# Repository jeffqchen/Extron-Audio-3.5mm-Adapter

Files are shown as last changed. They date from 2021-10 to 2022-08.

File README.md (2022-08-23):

# Extron Audio 3.5mm Adapter
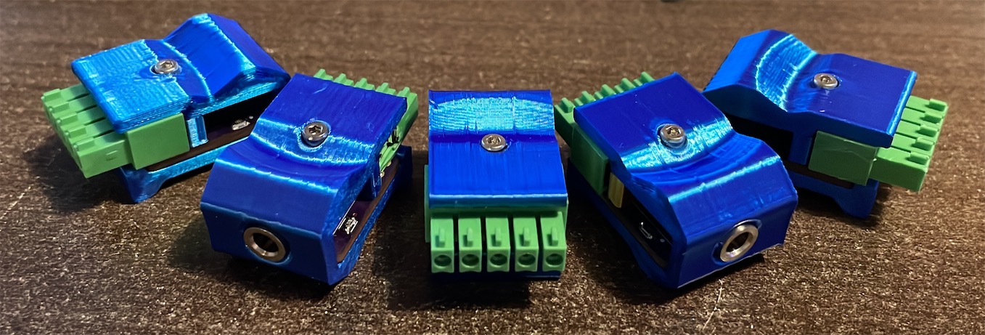
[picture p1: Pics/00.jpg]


This is an 3.5mm audio input/output adapter for the Extron switches. It conforms to the circuit design of the official CSM6 adapter to enable correct audio levels when balanced audio is adapted to unbalanced audio through a 3.5mm jack.

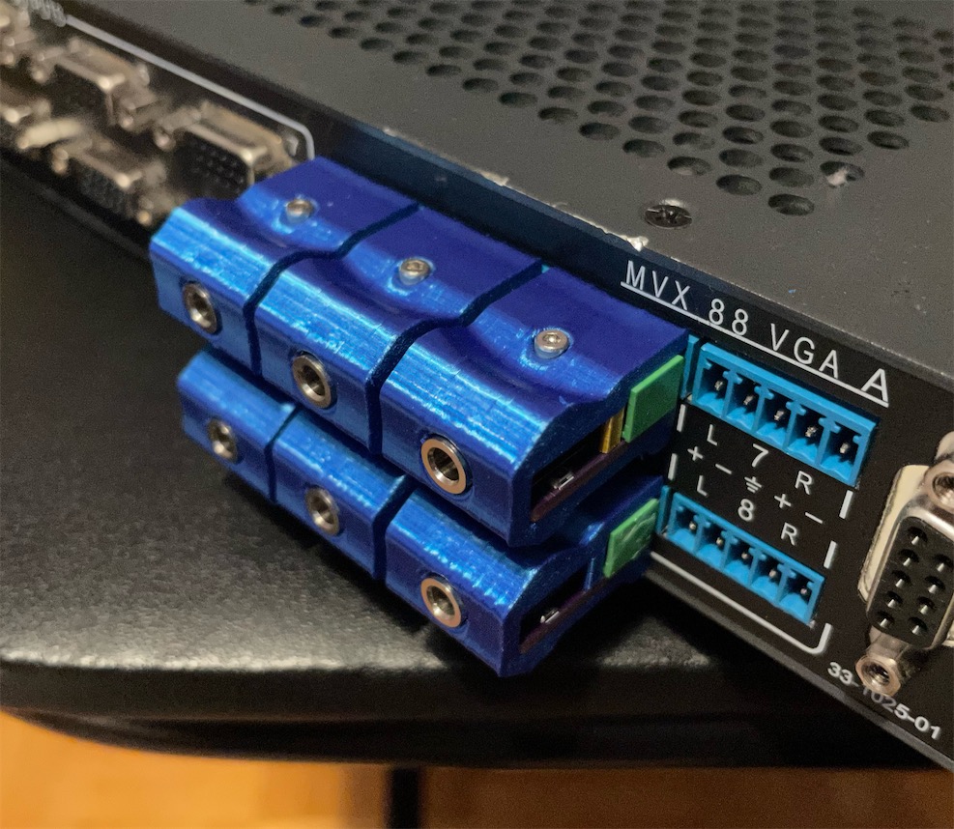
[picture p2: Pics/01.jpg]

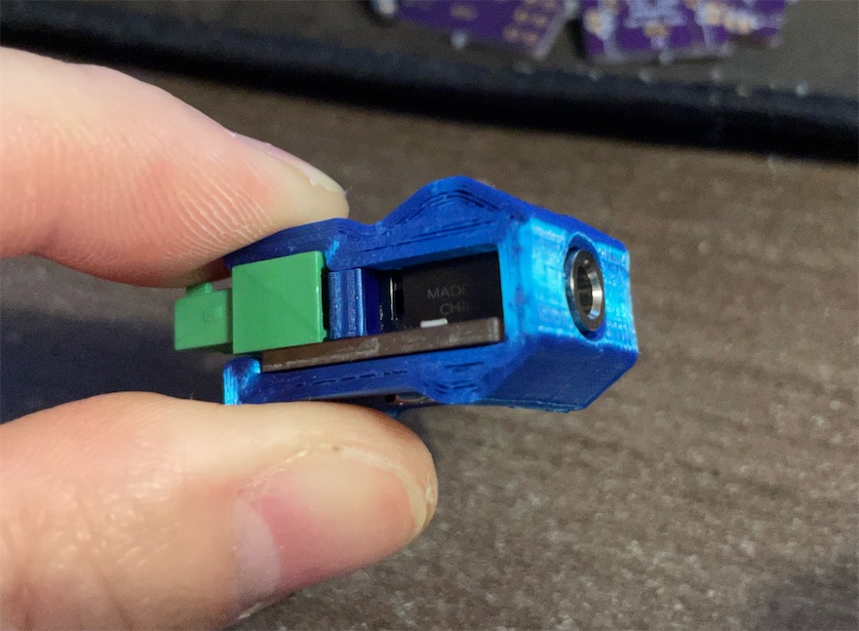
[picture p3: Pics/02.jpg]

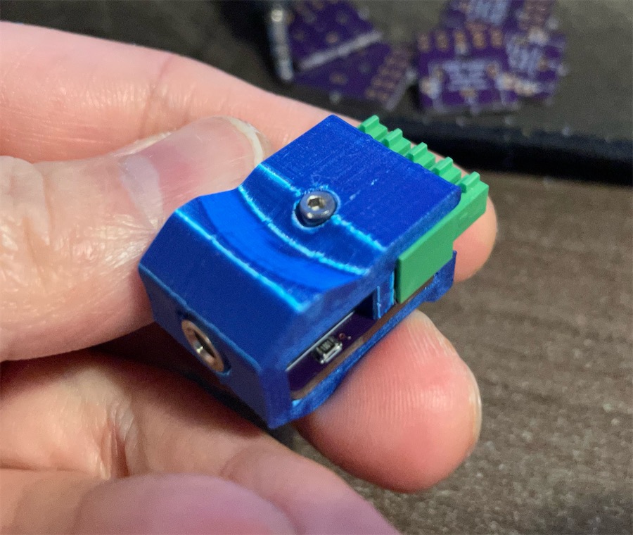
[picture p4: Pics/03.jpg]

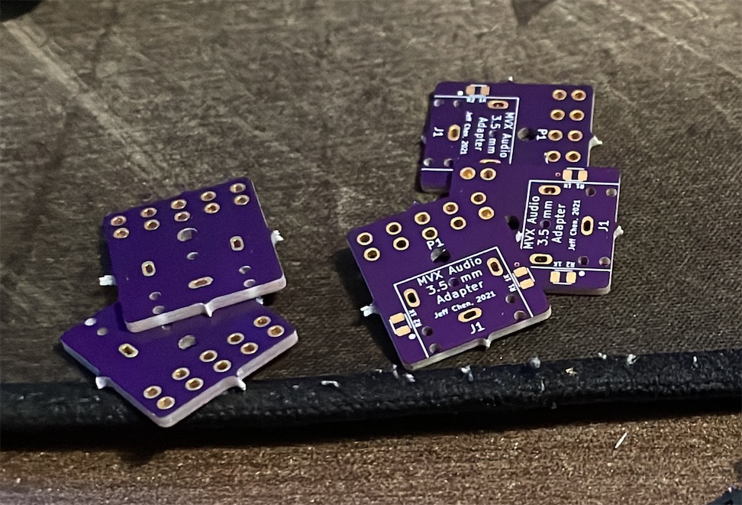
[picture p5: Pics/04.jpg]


-----------
## Parts

- [PCB](https://oshpark.com/shared_projects/oJI7PVwu)

- Terminal Plug - 5 pin, 3.5mm pitch, right angle, through-hole - [Link](https://github.com/jeffqchen/JeffParts/blob/main/Connectors/Phoenix%20Terminal%20Connector/Female%20PCB/info.md)

- Horizontal 3.5mm Headphone Jack - [Link](https://github.com/jeffqchen/JeffParts/blob/main/Connectors/3.5mm%20Audio%20Jack/Horizontal%203-Pin%20PCB/info.md)

- M2x12mm screw and hex nut - [Link](https://github.com/jeffqchen/JeffParts/blob/main/Parts/M2%20M3%20Hex%20Screw%20%26%20Nut/info.md)

- 2x Resistors 1K Ohm - SMD 0805/0603 OR through-hole 1/4W

- 3D Printed Shell

-----------
## 3D Printing The Shell

Print "Shell.stl" and "Stopper.stl".*

Print the shell sideways, without support.

Print the stopper standing, with the screw hole vertical.

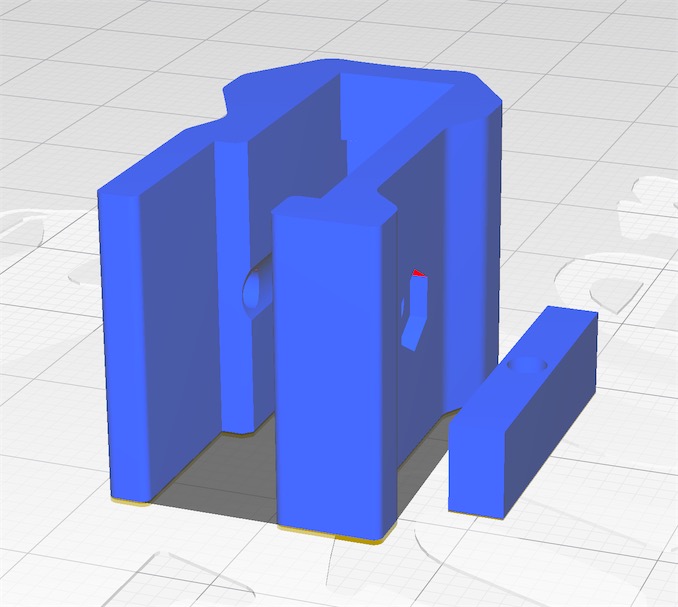
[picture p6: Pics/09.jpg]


***Note:** for Extron devices with an audio port that's flush with the shell (such as the RGB series), please use the shell called "Shell Flush.stl". The normal one does not seat properly and the connection will be loose.

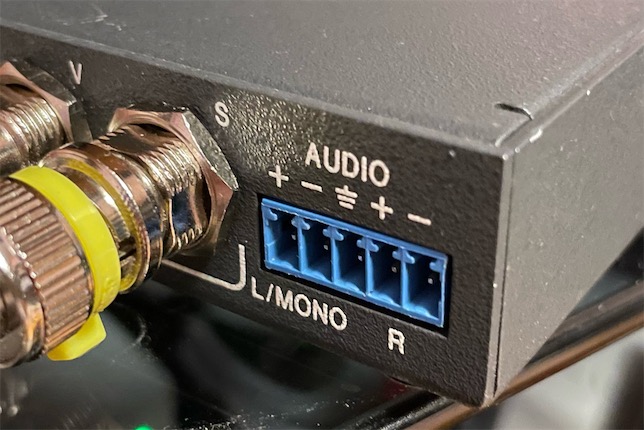
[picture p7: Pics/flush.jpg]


-----------
## Assembly

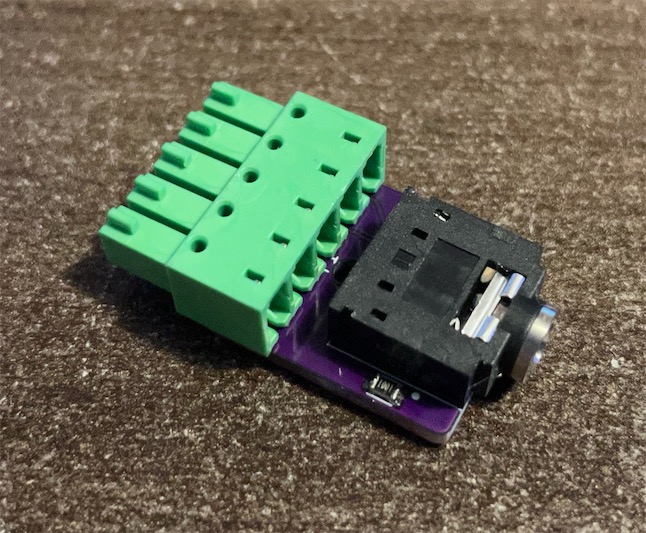
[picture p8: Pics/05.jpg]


Solder all the components onto the PCB. Trim the extruding leads on the bottom as much as possible, but perfection is not required.

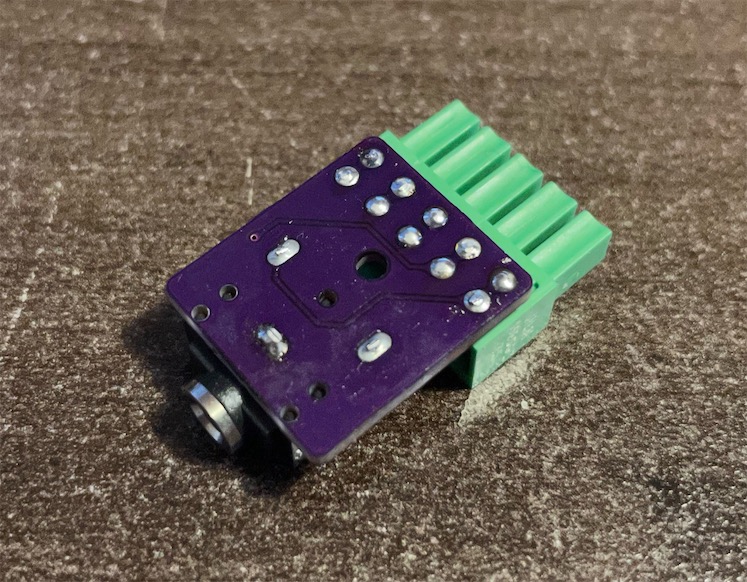
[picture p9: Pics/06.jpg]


Slide the PCB assembly into the 3D printed shell from the rear opening. Push it all the way in. Then slide the printed stopper piece into the center cavity. Then secure the entire assembly with the M2 screw and nut. DO NOT over-tighten the screw, or the shell might crack.




If you plan to use the adapters side-by-side on a CrossPoint switch, take a side cutter and cut off the two side walls of the terminal plug. This will ensure two adjacent plugs won't interfere with each other.

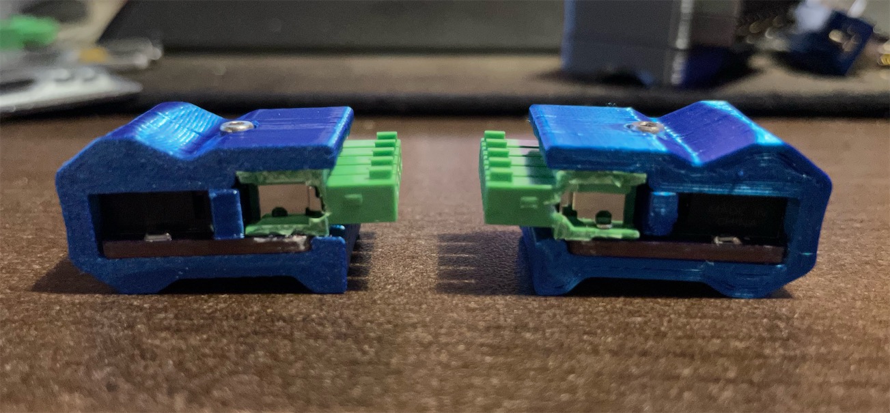
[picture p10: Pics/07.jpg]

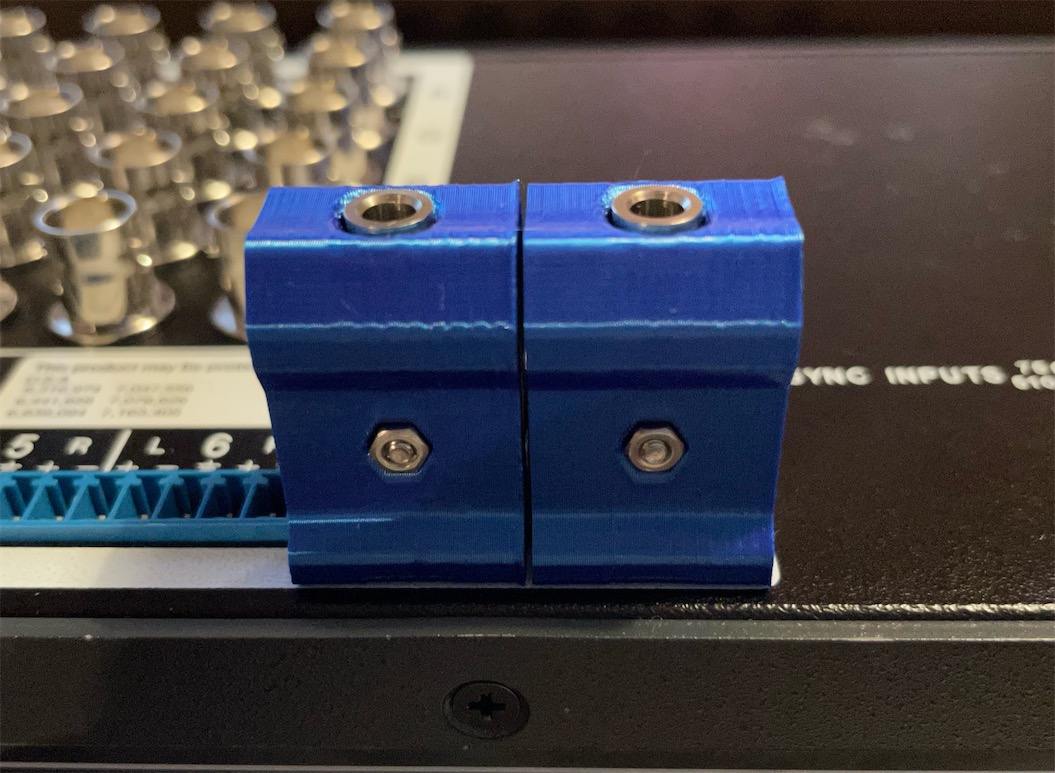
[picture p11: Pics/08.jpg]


--------
Special Thanks

qwertymodo (for the schematics of the original adapter)
- https://qwertymodo.com/
- https://twitter.com/qwertymodo

--------
Shield: [][cc-by-sa]

This work is licensed under a
[Creative Commons Attribution-ShareAlike 4.0 International License][cc-by-sa].

[][cc-by-sa]

[cc-by-sa]: http://creativecommons.org/licenses/by-sa/4.0/
[cc-by-sa-image]: https://licensebuttons.net/l/by-sa/4.0/88x31.png
[cc-by-sa-shield]: https://img.shields.io/badge/License-CC%20BY--SA%204.0-lightgrey.svg

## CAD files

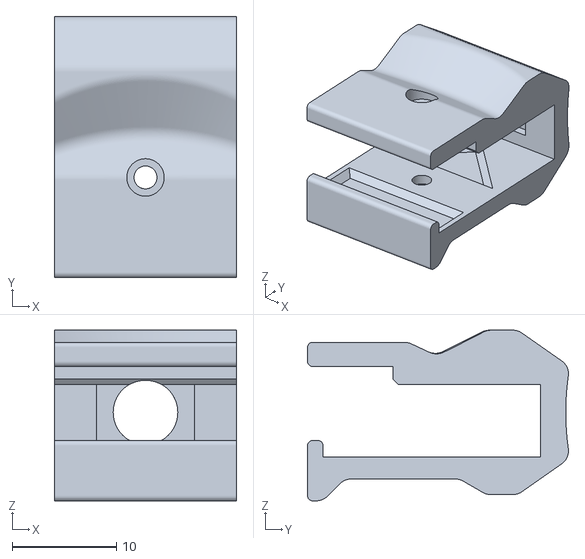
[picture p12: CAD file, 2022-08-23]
3D Print/Shell Flush.stl
17.5 x 25.1 x 16.4

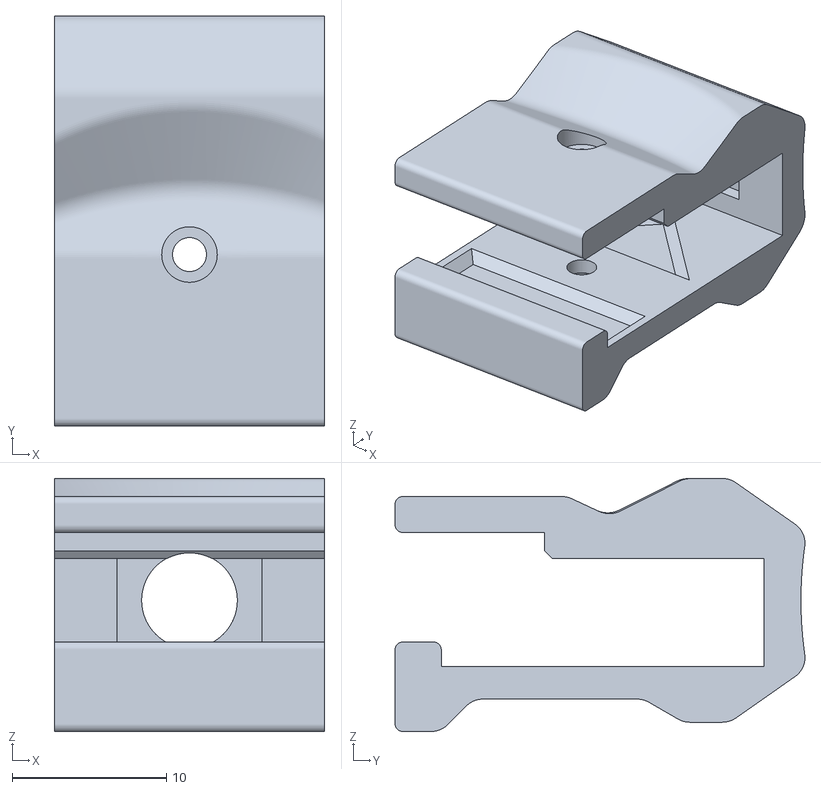
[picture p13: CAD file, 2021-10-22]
3D Print/Shell.stl
17.5 x 26.6 x 16.4

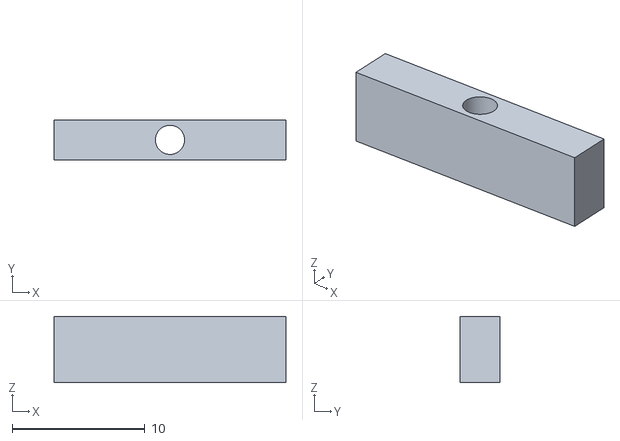
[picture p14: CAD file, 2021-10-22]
3D Print/Stopper.stl
17.5 x 3.00 x 5.00

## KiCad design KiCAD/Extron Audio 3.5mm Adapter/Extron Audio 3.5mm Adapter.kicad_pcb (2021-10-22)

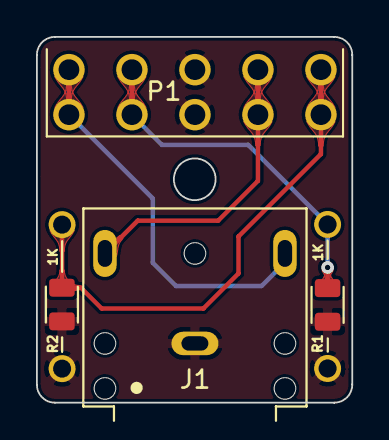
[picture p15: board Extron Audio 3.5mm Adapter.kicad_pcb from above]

Board: 2 copper layers, 17.5 x 20.3 mm, 6 parts (0 on the bottom side), 5 nets.

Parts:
J1: 3.5mm_Jack_Horizontal; 3.5mm_jack_horizontal
P1: terminal_5pin; terminal_plug_5pin
R1, R2: 1K_SMD; Resistor_SMD_0805
T_R1, T_R2: 1K_SMD; Resistor_Through_Hole

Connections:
/GND: J1.1, P1.3, R1.2, R2.2, T_R1.2, T_R2.2
/L_Tip: J1.2, P1.1
/R_Ring: J1.3, P1.4
unnamed: P1.2, R1.1, T_R1.1
unnamed: P1.5, R2.1, T_R2.1

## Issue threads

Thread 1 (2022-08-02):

No space in shell for through hole resistor

the0remora, 2022-08-02:
I am currently running a test print to confirm this but there was a void left for the 3.5mm jack but I don't see one where the legs would be for a through hole. If it is an issue can you provide the source of the STL? I am willing to fix it and send it back

jeffqchen, 2022-08-22:
> I am currently running a test print to confirm this but there was a void left for the 3.5mm jack but I don't see one where the legs would be for a through hole. If it is an issue can you provide the source of the STL? I am willing to fix it and send it back

That was so that you could use either an SMD or a through hole. Do not populate both of them as that will be an issue.

If the legs of the through hole resistors would be a problem, you might wanna trim the legs then solder them from the top side to make sure the bottom is flat.

the0remora, 2022-08-23:
If they are trimmed flush after soldier with minimal solder it's not an issue. I hase started trimming them before soldering and that works well. Closing this by saying these to print well in resin.

Closed 2022-08-23.

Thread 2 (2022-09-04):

Aliexpress link for the terminal plug is down

stefanpausch, 2022-09-04:
Hello,

the Aliexpress link for the Terminal plug is down. Do you have an alternative Aliexpress link / search term?

ihategravel2, 2025-09-13:
I've ran into this issue as well. I searched for about an hour trying to find an alternative but have had no luck. I manged to find a official one but requires a minimum order of 50 for like $200.

jeffqchen, 2025-09-13:
> I've ran into this issue as well. I searched for about an hour trying to find an alternative but have had no luck. I manged to find a official one but requires a minimum order of 50 for like $200.

I found one but haven't verified it yet:
https://www.aliexpress.com/item/1005003834518054.html

Basically the keyword is KF2EDGA, 3.5mm, 5P (pins/positions)

ihategravel2, 2025-09-13:
Thanks. I'll order one of those and see if it fits. Will look around more
with the keywords you suggested as well.

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

ihategravel2, 2025-09-13:
Think I found it on LCSC. Was actually cheaper then Aliexpress. Bought out the 16 that was on there.
https://jlcpcb.com/partdetail/Cixi_KefaElec-KF2EDGA_3_55P/C6394076

jeffqchen, 2025-09-13:
Alright, please let me know if that one works.

ihategravel2, 2025-09-13:
Here's the official phoenix connector page. Has a 3d model, footprint, and schem.
https://www.phoenixcontact.com/en-us/products/pcb-header-imc-15-5-g-35-p20-thr-1830443

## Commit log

2021-10-22 Initial upload
    [Extron Audio 3.5mm Adapter-B_Mask.gbr, Extron Audio 3.5mm Adapter-B_Paste.gbr, Extron Audio 3.5mm Adapter-B_SilkS.gbr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]
2022-08-23 Create Shell Flush.stl
    [Shell Flush.stl]

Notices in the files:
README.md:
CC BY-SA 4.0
